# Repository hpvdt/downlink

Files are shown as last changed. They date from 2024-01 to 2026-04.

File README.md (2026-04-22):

# downlink
General data downlink system for our vehicles

## Known USB Issue

The STM32F103 series of microcontrollers needs an external 1.5&nbsp;kOhm pullup resistor to the 3.3&nbsp;V supply rail on the D+ line for proper used, as per table 3 in section 2.1 of [AN4879](https://www.st.com/resource/en/application_note/an4879-introduction-to-usb-hardware-and-pcb-guidelines-using-stm32-mcus-stmicroelectronics.pdf). 

This explains why previous boards failed to work with USB communications. The TITAN 2022 board managed to work because there was a 10&nbsp;kOhm resistor for this pullup, likely the minimum needed for this.

There is also no need for the 22&nbsp;Ohm resistors on the USB data lines.

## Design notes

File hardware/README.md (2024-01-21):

# Hardware

These are the designs for the downlink board.

## USB Issues

After assembling V1.2 of the board, it was found trhat the USB functionality of the chip doesn't work. This issue seems to come from having the chip on the board, as flashing the code on STM32's on dev boards worked as intended. 

Further tests to try and isolate the root cause were inconclusive, installing a new chip didn't help; transplating a working chip from a dev board to this board failed, but worked when returned to its original dev board; running wires from a dev board to the 22 ohm resistors worked. So it seems to just affect chips that are mounted directly on the board.

So there is no known root cause, at least these boards can be used as RPi HATs until revised.

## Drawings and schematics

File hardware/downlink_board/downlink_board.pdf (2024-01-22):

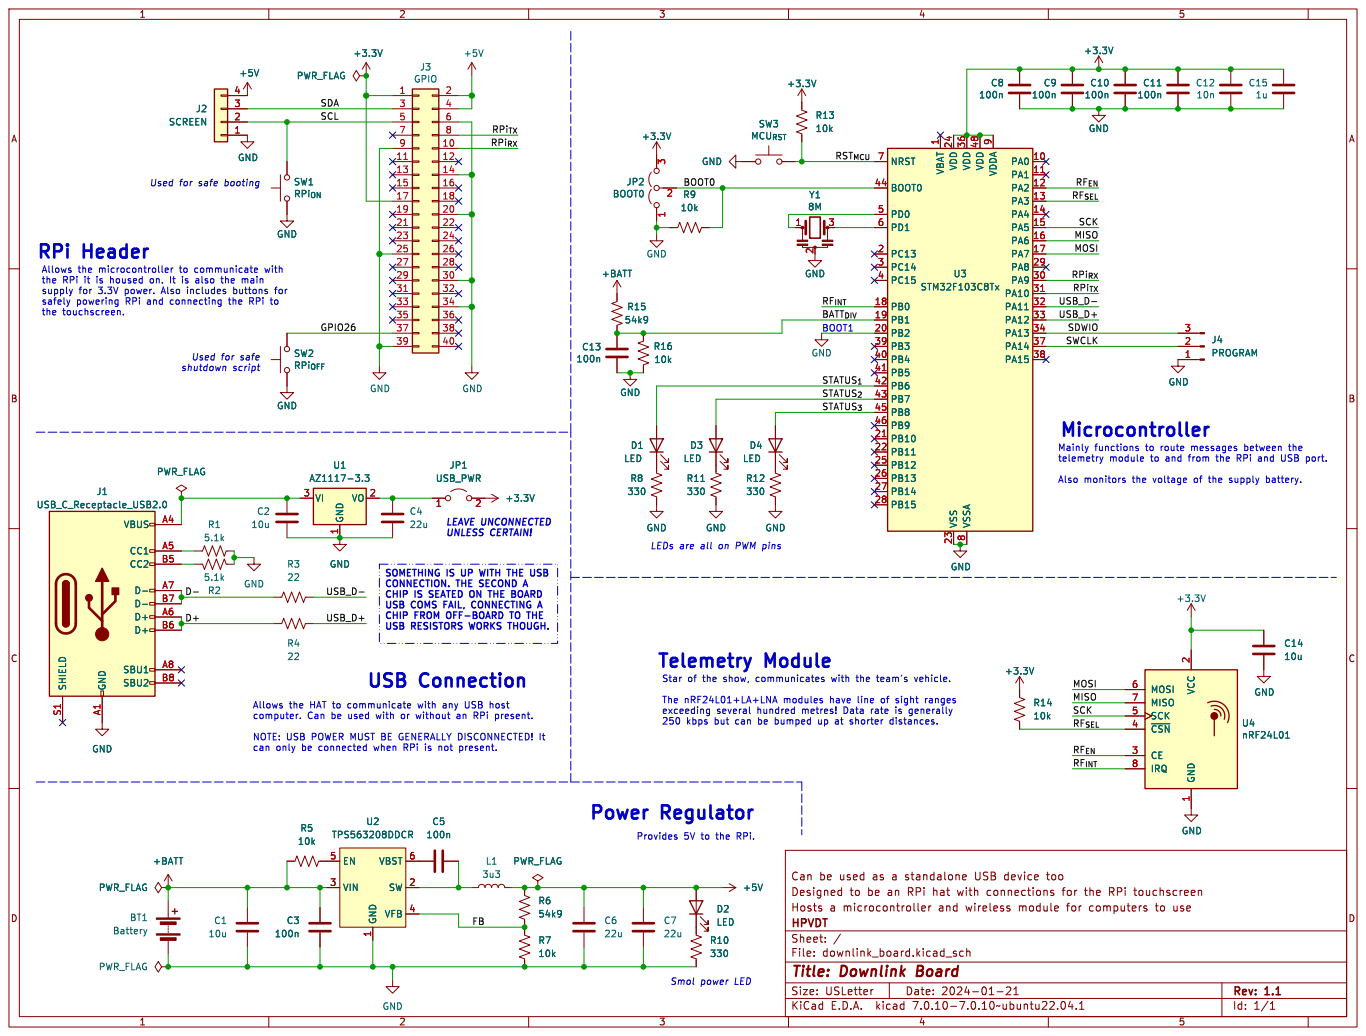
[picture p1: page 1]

1 PA0 10 PA1 11 PA2 12 PA3 13 PA4 14 PA5 15 PA6 16 PA7 17 PB0 18 PB1 19 PC13 2 PB2 20 PB10 21 PB11 22 VSS 23 VDD 24 PB12 25 PB13 26 PB14 27 PB15 28 PA8 29 PC14 3 PA9 30 PA10 31 PA11 32 PA12 33 PA13 34 VDD 36 PA14 37 PA15 38 PB3 39 PC15 4 PB4 40 PB5 41 PB6 42 PB7 43 BOOT0 44 PB8 45 PB9 46 VDD 48 PD0 5 PD1 6 NRST 7 VSSA

RF_{INT} Used for safe booting

the RPi it is housed on. It is also the main

UNLESS CERTAIN! Used for safe

LEDs are all on PWM pins

CONNECTION. THE SECOND A
CHIP IS SEATED ON THE BOARD
USB COMS FAIL, CONNECTING A

2 CE 3 ~{CSN} 4 SCK 5 MOSI 6 MISO 7

1 SW 2 VIN 3 VFB 4 EN 5 VBST 6 U2 TPS563208DDCR

1 SW 2 VIN 3 VFB 4 EN 5 VBST 6 R6

Id: 1/1 Title: Downlink Board

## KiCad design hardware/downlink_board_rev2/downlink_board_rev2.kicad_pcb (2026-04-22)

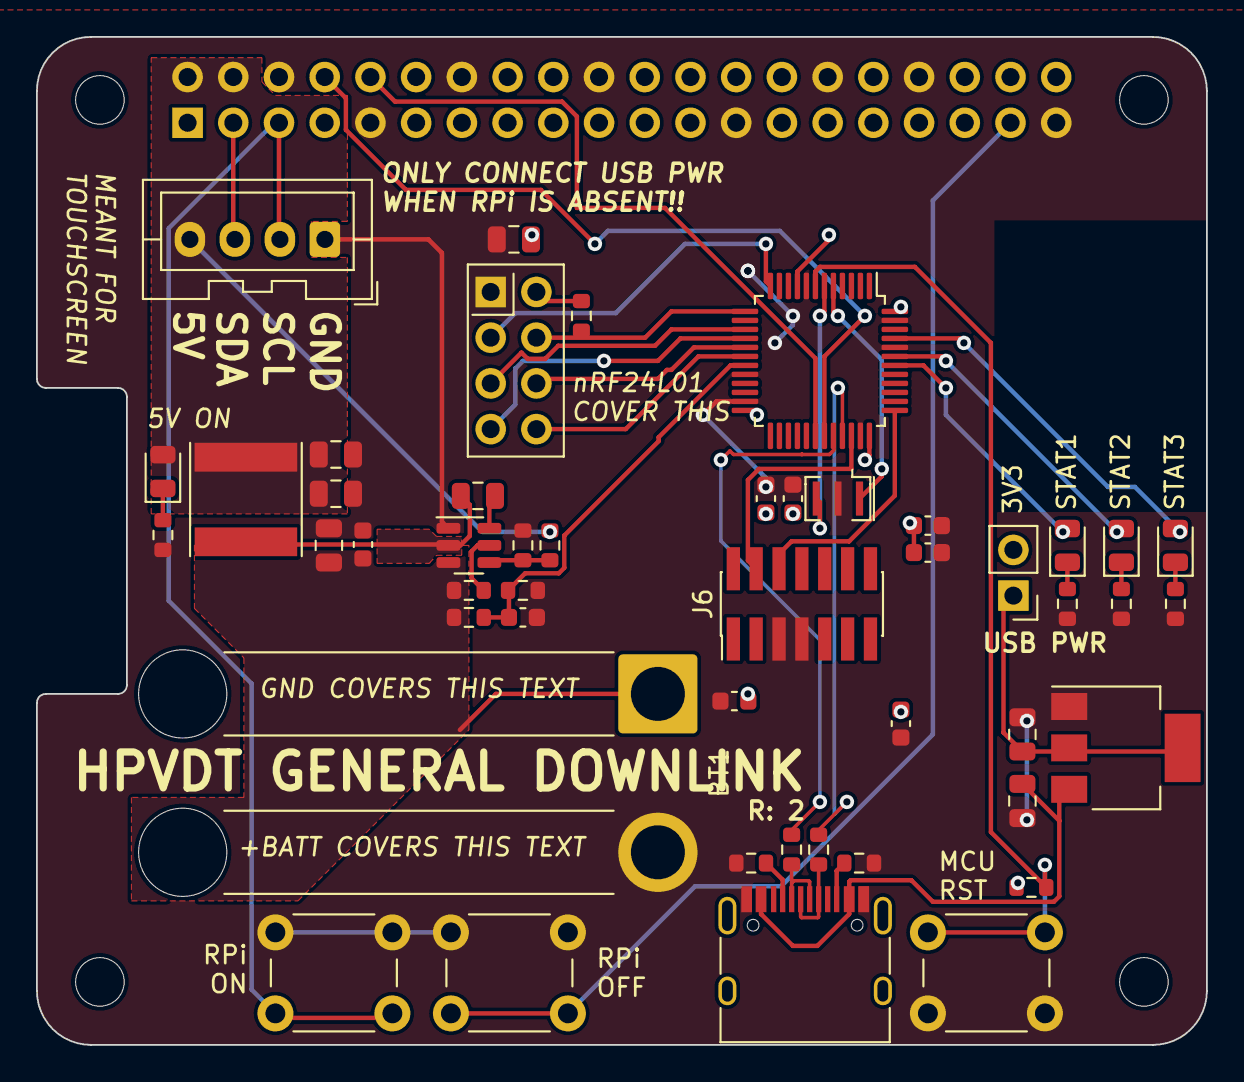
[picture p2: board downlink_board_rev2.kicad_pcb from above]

Board: 2 copper layers, 65.0 x 56.0 mm, 53 parts (1 on the bottom side), 40 nets.

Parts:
BT1: Battery; SolderWire-2.5sqmm_1x02_P8.8mm_D2.4mm_OD4.4mm_Relief
C1, C2, C14: 10u; C_0805_2012Metric
C3, C8, C9, C10, C11, C13: 100n; C_0603_1608Metric
C4, C6, C7: 22u; C_0805_2012Metric
C5: 100n; C_0805_2012Metric
C12: 10n; C_0603_1608Metric
C15: 1u; C_0603_1608Metric
D1, D2, D3, D4: LED; LED_0805_2012Metric
J1: USB_C_Receptacle_USB2.0; USB_C_Receptacle_HRO_TYPE-C-31-M-12
J2: SCREEN; JST_XA_B04B-XASK-1_1x04_P2.50mm_Vertical
J3: GPIO; PinSocket_2x20_P2.54mm_Vertical
J6: Conn_ST_STDC14; PinHeader_2x07_P1.27mm_Vertical_SMD
JP1: USB_PWR; PinHeader_1x02_P2.54mm_Vertical
L1: 3u3; L_Taiyo-Yuden_NR-60xx
MH1, MH2, MH3, MH4: MountingHole_2.7mm_M2.5
R1, R2: 5.1k; R_0603_1608Metric
R3, R4: 22; R_0603_1608Metric
R5, R7, R13, R14, R16: 10k; R_0603_1608Metric
R6, R15: 54k9; R_0603_1608Metric
R8, R10, R11, R12: 330; R_0603_1608Metric
SW1: RPi_{ON}; SW_PUSH_6mm_H4.3mm
SW2: RPi_{OFF}; SW_PUSH_6mm_H4.3mm
SW3: MCU_{RST}; SW_PUSH_6mm_H4.3mm
U1: AZ1117-3.3; SOT-223-3_TabPin2
U2: TPS563208DDCR; TSOT-23-6
U3: STM32F103C8Tx; LQFP-48_7x7mm_P0.5mm
U4: nRF24L01; nRF24L01_Breakout
Y1: 8M; Resonator_SMD_Murata_CSTxExxV-3Pin_3.0x1.1mm

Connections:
+3.3V: C8.2, C9.2, C10.2, C11.2, C12.2, C14.2, C15.2, J3.1, J3.17, JP1.2 (B), R13.2, R14.2, U3.9 (VDDA), U3.24 (VDD), U3.36 (VDD), U3.48 (VDD), U4.2 (VCC)
+5V: C6.2, C7.2, D2.2 (A), J2.4, J3.2, J3.4, L1.2, R6.1
+BATT: BT1.1 (+), C1.2, C3.2, R5.1, R15.2, U2.3 (VIN)
/BATT_{DIV}: C13.2, R15.1, R16.2, U3.19 (PB1)
/D+: J1.A6 (D+), J1.B6 (D+), R4.1
/D-: J1.A7 (D-), J1.B7 (D-), R3.1
/FB: R6.2, R7.2, U2.4 (VFB)
/GPIO26: J3.37, SW2.2
/MISO: U3.16 (PA6), U4.7 (MISO)
/MOSI: U3.17 (PA7), U4.6 (MOSI)
/RF_{EN}: U3.12 (PA2), U4.3 (CE)
/RF_{INT}: U3.18 (PB0), U4.8 (IRQ)
/RF_{SEL}: R14.1, U3.13 (PA3), U4.4 (~CSN)
/RPi_{RX}: J3.10, U3.30 (PA9)
/RPi_{TX}: J3.8, U3.31 (PA10)
/RST_{MCU}: R13.1, SW3.2, U3.7 (NRST)
/SCK: U3.15 (PA5), U4.5 (SCK)
/SCL: J2.2, J3.5, SW1.2
/SDA: J2.3, J3.3
/SDWIO: J6.4 (JTMS/SWDIO), U3.34 (PA13)
/STATUS_{1}: D1.2 (A), U3.42 (PB6)
/STATUS_{2}: D3.2 (A), U3.43 (PB7)
/STATUS_{3}: D4.2 (A), U3.45 (PB8)
/SWCLK: J6.6 (JCLK/SWCLK), U3.37 (PA14)
/USB_D+: R4.2, U3.33 (PA12)
/USB_D-: R3.2, U3.32 (PA11)
GND: BT1.2 (-), C1.1, C2.1, C3.1, C4.1, C6.1, C7.1, C8.1, C9.1, C10.1, C11.1, C12.1, C13.1, C14.1, C15.1, J1.A1 (GND), J1.A12 (GND), J1.B1 (GND), J1.B12 (GND), J2.1, J3.6, J3.9, J3.14, J3.20, J3.25, J3.30, J3.34, J3.39, J6.5 (GND), J6.7 (GND), R1.2, R2.2, R7.1, R8.1, R10.1, R11.1, R12.1, R16.1, SW1.1, SW2.1, SW3.1, U1.1 (GND), U2.1 (GND), U3.8 (VSSA), U3.20 (PB2), U3.23 (VSS), U3.35 (VSS), U3.44 (BOOT0), U3.47 (VSS), U4.1 (GND), Y1.2
unnamed: D1.1 (K), R8.2
unnamed: D2.1 (K), R10.2
unnamed: D3.1 (K), R11.2
unnamed: D4.1 (K), R12.2
unnamed: J1.A5 (CC1), R1.1
unnamed: J1.B5 (CC2), R2.1
unnamed: C4.2, JP1.1 (A), U1.2 (VO)
unnamed: C2.2, J1.A4 (VBUS), J1.A9 (VBUS), J1.B4 (VBUS), J1.B9 (VBUS), U1.3 (VI)
unnamed: R5.2, U2.5 (EN)
unnamed: C5.2, L1.1, U2.2 (SW)
unnamed: C5.1, U2.6 (VBST)
unnamed: U3.5 (PD0), Y1.1
unnamed: U3.6 (PD1), Y1.3

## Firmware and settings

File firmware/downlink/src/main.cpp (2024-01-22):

#include <Arduino.h>

#ifdef STM32
HardwareSerial RPi(PA10, PA9);
#define Serial RPi
#endif

const int ledPins[] = {PB6, PB7, PB8};

void setup() {
  for (int i = 0; i < 3; i++) pinMode(ledPins[i], OUTPUT);
  Serial.begin(115200);
  for (int i = 0; i < 3; i++) digitalWrite(ledPins[i], HIGH);
}

void loop() {
  for (int i = 0; i < 3; i++) digitalWrite(ledPins[i], HIGH);
  delay(1000);
  for (int i = 0; i < 3; i++) digitalWrite(ledPins[i], LOW);
  delay(1000);
  Serial.println(millis());
}

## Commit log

2023-11-30 Completed initial schematic
    [downlink_board.kicad_pcb, downlink_board.kicad_sch]
2023-11-30 Added PWM message for LEDs
    [downlink_board.kicad_sch]
2023-12-05 Revised input caps for vreg
    [downlink_board.kicad_sch]
2023-12-05 Completed Rev 1.0 layout
    [downlink_board.kicad_pcb, downlink_board.kicad_sch]
2023-12-05 Layout Rev 1.1
    Added a keepout area under where the antenna header will go to ensure that if it scratches the board no shorts will occur.
    [downlink_board.kicad_pcb]
2023-12-06 Layout V1.2, no more USB overhang
    [downlink_board.kicad_pcb]
2023-12-06 Changed folder organization
    [downlink_board.kicad_pcb, downlink_board.kicad_sch]
2023-12-19 BOM adjustments
    [downlink_board.kicad_pcb, downlink_board.kicad_sch]
2024-01-21 Recording USB issues
    [downlink_board.kicad_pcb, downlink_board.kicad_sch]
2024-01-22 Updated schematic with warning
    [downlink_board.kicad_sch]
2024-06-14 Initial commit of rev2 downlink
    [downlink_board_rev2.kicad_pcb, downlink_board_rev2.kicad_sch]
2024-07-06 Updated to Rev 2
    [downlink_board_rev2.kicad_pcb, downlink_board_rev2.kicad_sch]
2024-07-06 Updated the debugger header connections
    Added TX RX connection with the header
    Deleted BOOT1
    [downlink_board_rev2.kicad_sch]
2024-07-08 Finished rerouting everything
    rerouted everything, resolved the hardware conflict between the header and the NRF module.
    [downlink_board_rev2.kicad_pcb, downlink_board_rev2.kicad_sch]
2024-07-09 Update on reroutes
    Updated the routing such that the routes doesn't go to the edge of the board just in case.
    [downlink_board_rev2.kicad_pcb]
2024-07-16 Updated PCB & slight rerouting
    Updated PCB to match schematic headers; moved microcontroller closer to USB port
    [downlink_board_rev2.kicad_pcb]
2024-07-16 Moved caps closer to microcontroller
    Moved the four 100nF capacitors closer to the microcontroller (had previously mistakenly moved them farther away)
    [downlink_board_rev2.kicad_pcb]
2024-07-16 Minor relocation of 10n, 1u caps
    [downlink_board_rev2.kicad_pcb]
2026-04-22 Document known USB issue for STM32F103
    Added information about USB issues related to STM32F103 microcontrollers.
